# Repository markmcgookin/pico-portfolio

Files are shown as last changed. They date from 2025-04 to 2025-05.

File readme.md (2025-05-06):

# The Pico Portfolio

This project is an attempt to create a maker-friendly keyboard using the same form factor as the original Atari Portfolio keyboard. 

What started out as an attempt to re-use broken atari portfolio keyboards in new/modern projects hit a wall when tryign to remove the keyboard from its original housing. The housing on the actual Atari Portfolio is very custom for the device and case, and doesn't lend itself well to re-modeling, due to the makeup of the matrix, individual keys and rubber membrane. 

There are files here (in original-portfolio-files) that can be used to turn a *real* atari portfolio keyboard into a USB device with a Raspberry Pi Pico, however, the aim of this repo is to simply create a new, custom board that requires no legacy hardware, is maker friendly, and can be customised with only a 3D printer and some circuitpython.

## Why the portfolio?

Because of its form factor, it is somewhere between the very popular 'blackberry' style handheld keyboard, and the smallest ortholiniar keyboards used in maker projects like cyberdecks. This gives a full keyboard with modifier keys, sacrificing 'touch typing' ability for ease of use by someone who is not an expert in multi-layer keyboard setups. 

Also, John Connor hacked an ATM with one in T2 and I have been in love with them ever since. 

## Why the pico? 

Basically, I had a few picow's lying around and I know the device well. It has lots of GPIO pins and pads under the USB port that make it very easy to solder wires to use as a neat form factor for this sort of thing. 

## Why circuitpython

I plan to add a QMK version to this in the future, and I don't think it would be too hard, but when writing my original version of the firmware for the *real* Portfolio keyboard I ended up using CircuitPython because I knew/understood it well, and was able to make progress. My initial attempts at QMK for that build failed, so I've just stuck with it as it makes debugging super easy. I personally prefer it to MicroPython, but if anyone wants to translate it, please be my guest.

However, now that I know the exact matrix setup, I think QMK would be pretty easy to add to this as an option as well. 

# Setup
You will need to flash a Pico with CircuitPython 9.X (at the time of writing I am using 9.2.7 for the PicoW) - once that is done, connect it to your computer and drop all the files/folders in the `device` folder onto the device. That should load up everything required.

Then it is a matter of printing the STLs in the `3d-models -> stls -> buttons` folder or creating your own. I have included backups of my Fusion360 project in `3d-models -> fusion` should anyone wish to modify things and export their own. I will also include models for the circuitboard with switches and pico in place hopefully will help people wanting to make their own.

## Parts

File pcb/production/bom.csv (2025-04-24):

Designator | Footprint | Quantity | Value | LCSC Part #
D1, D10, D11, D12, D13, D14, D15, D16, D17, D18, D19, D2, D20, D21, D22, D23, D24, D25, D26, D27, D28, D29, D3, D30, D31, D32, D33, D34, D35, D36, D37, D38, D39, D4, D40, D41, D42, D43, D44, D45, D46, D47, D48, D49, D5, D50, D51, D52, D53, D54, D55, D56, D57, D58, D59, D6, D60, D61, D62, D63, D64, D7, D8, D9 | SOD-123_L2.8-W1.8-LS3.7-RD | 64 | 1N4148
SW1, SW10, SW11, SW12, SW13, SW14, SW15, SW16, SW17, SW18, SW19, SW2, SW20, SW21, SW22, SW23, SW24, SW25, SW26, SW27, SW28, SW29, SW3, SW30, SW31, SW32, SW33, SW34, SW35, SW36, SW37, SW38, SW39, SW4, SW40, SW41, SW42, SW43, SW44, SW45, SW46, SW47, SW48, SW49, SW5, SW50, SW51, SW52, SW53, SW54, SW55, SW56, SW57, SW58, SW59, SW6, SW60, SW61, SW62, SW63, SW64, SW7, SW8, SW9 | SW-SMD_4P-L6.2-W6.2-P4.50-LS8.6 | 64 | SW_Push

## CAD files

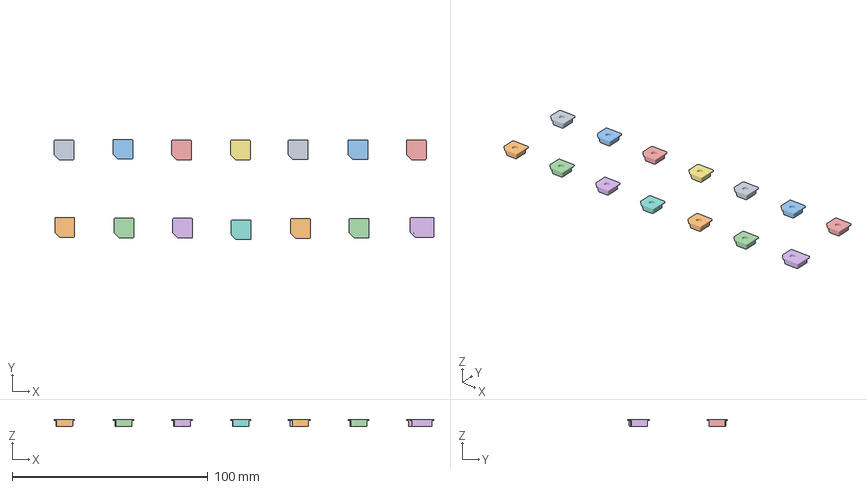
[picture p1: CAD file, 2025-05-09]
3d-models/printing/Top Row - With Lettering.3mf
194.3 x 51.4 x 3.60 mm
Pico Portfolio Keyboard With Keys v48.stl_1
Pico Portfolio Keyboard With Keys v48.stl_2
Pico Portfolio Keyboard With Keys v48.stl_3
Pico Portfolio Keyboard With Keys v48.stl_4
Pico Portfolio Keyboard With Keys v48.stl_5
Pico Portfolio Keyboard With Keys v48.stl_6
Pico Portfolio Keyboard With Keys v48.stl_7
Pico Portfolio Keyboard With Keys v48.stl_8
Pico Portfolio Keyboard With Keys v48.stl_9
Pico Portfolio Keyboard With Keys v48.stl_10
Pico Portfolio Keyboard With Keys v48.stl_11
Pico Portfolio Keyboard With Keys v48.stl_12
Pico Portfolio Keyboard With Keys v48.stl_13
Pico Portfolio Keyboard With Keys v48.stl_14
Pico Portfolio Keyboard With Keys v48.stl_15
Pico Portfolio Keyboard With Keys v48.stl_16
Pico Portfolio Keyboard With Keys v48.stl_17
Pico Portfolio Keyboard With Keys v48.stl_18
Pico Portfolio Keyboard With Keys v48.stl_19
Pico Portfolio Keyboard With Keys v48.stl_20
Pico Portfolio Keyboard With Keys v48.stl_21
Pico Portfolio Keyboard With Keys v48.stl_22
Pico Portfolio Keyboard With Keys v48.stl_23
Pico Portfolio Keyboard With Keys v48.stl_24
Pico Portfolio Keyboard With Keys v48.stl_25
Pico Portfolio Keyboard With Keys v48.stl_26
Pico Portfolio Keyboard With Keys v48.stl_27
Pico Portfolio Keyboard With Keys v48.stl_28
Pico Portfolio Keyboard With Keys v48.stl_29
Pico Portfolio Keyboard With Keys v48.stl_30
Pico Portfolio Keyboard With Keys v48.stl_31
Pico Portfolio Keyboard With Keys v48.stl_32
Pico Portfolio Keyboard With Keys v48.stl_33
Pico Portfolio Keyboard With Keys v48.stl_34
Pico Portfolio Keyboard With Keys v48.stl_35
Pico Portfolio Keyboard With Keys v48.stl_36
Pico Portfolio Keyboard With Keys v48.stl_37
Pico Portfolio Keyboard With Keys v48.stl_38
Pico Portfolio Keyboard With Keys v48.stl_39
Pico Portfolio Keyboard With Keys v48.stl_40
Pico Portfolio Keyboard With Keys v48.stl_41
Pico Portfolio Keyboard With Keys v48.stl_42
Pico Portfolio Keyboard With Keys v48.stl_43
Pico Portfolio Keyboard With Keys v48.stl_44
Pico Portfolio Keyboard With Keys v48.stl_45
Pico Portfolio Keyboard With Keys v48.stl_46

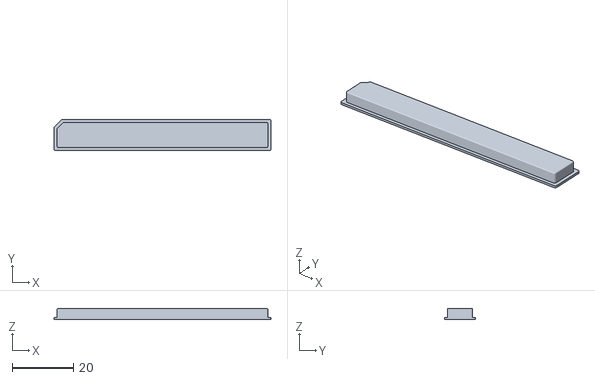
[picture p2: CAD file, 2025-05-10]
3d-models/stls/Spacebar.stl
71.0 x 10.2 x 3.60

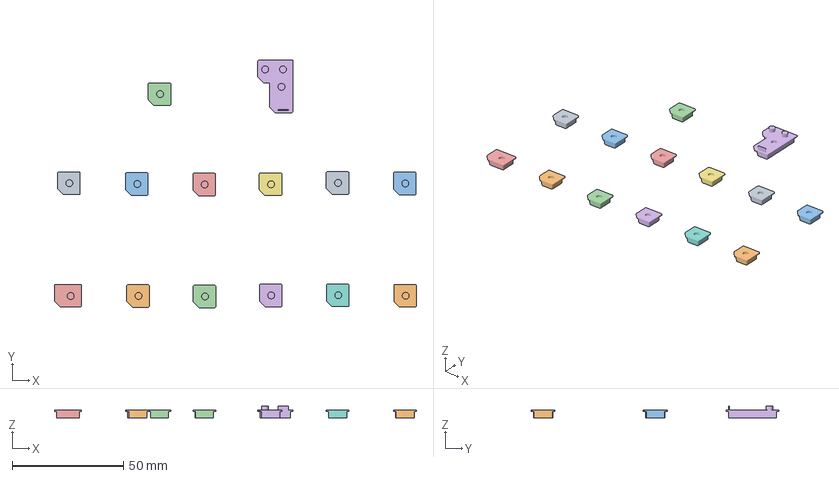
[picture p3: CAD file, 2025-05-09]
3d-models/printing/Second Row - With Lettering.3mf
162.7 x 111.4 x 5.60 mm
Pico Portfolio Keyboard With Keys v50.stl_1
Pico Portfolio Keyboard With Keys v50.stl_2
Pico Portfolio Keyboard With Keys v50.stl_3
Pico Portfolio Keyboard With Keys v50.stl_4
Pico Portfolio Keyboard With Keys v50.stl_5
Pico Portfolio Keyboard With Keys v50.stl_6
Pico Portfolio Keyboard With Keys v50.stl_7
Pico Portfolio Keyboard With Keys v50.stl_8
Pico Portfolio Keyboard With Keys v50.stl_9
Pico Portfolio Keyboard With Keys v50.stl_10
Pico Portfolio Keyboard With Keys v50.stl_11
Pico Portfolio Keyboard With Keys v50.stl_12
Pico Portfolio Keyboard With Keys v50.stl_13
Pico Portfolio Keyboard With Keys v50.stl_14
Pico Portfolio Keyboard With Keys v50.stl_15
Pico Portfolio Keyboard With Keys v50.stl_16
Pico Portfolio Keyboard With Keys v50.stl_17
Pico Portfolio Keyboard With Keys v50.stl_18
Pico Portfolio Keyboard With Keys v50.stl_19
Pico Portfolio Keyboard With Keys v50.stl_20
Pico Portfolio Keyboard With Keys v50.stl_21
Pico Portfolio Keyboard With Keys v50.stl_22
Pico Portfolio Keyboard With Keys v50.stl_23
Pico Portfolio Keyboard With Keys v50.stl_24
Pico Portfolio Keyboard With Keys v50.stl_25
Pico Portfolio Keyboard With Keys v50.stl_26
Pico Portfolio Keyboard With Keys v50.stl_27
Pico Portfolio Keyboard With Keys v50.stl_28
Pico Portfolio Keyboard With Keys v50.stl_29
Pico Portfolio Keyboard With Keys v50.stl_30
Pico Portfolio Keyboard With Keys v50.stl_31

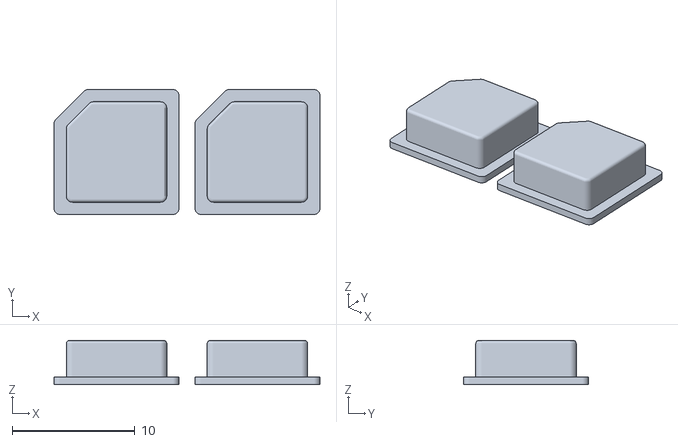
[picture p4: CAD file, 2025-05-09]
3d-models/stls/Semi Colon and Quote.stl
21.7 x 10.2 x 3.60

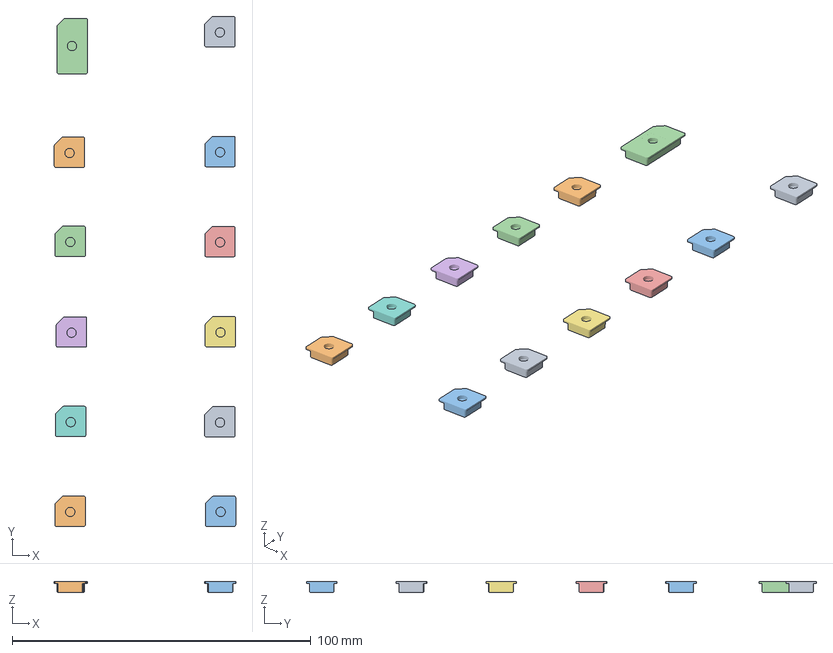
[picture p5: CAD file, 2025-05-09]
3d-models/printing/Third Row - With Lettering.3mf
60.8 x 170.8 x 3.62 mm
Third Row.stl_1
Third Row.stl_2
Third Row.stl_3
Third Row.stl_4
Third Row.stl_5
Third Row.stl_6
Third Row.stl_7
Third Row.stl_8
Third Row.stl_9
Third Row.stl_10
Third Row.stl_11
Third Row.stl_12
Third Row.stl_13
Third Row.stl_14
Third Row.stl_15
Third Row.stl_16
Third Row.stl_17
Third Row.stl_18
Third Row.stl_19
Third Row.stl_20
Third Row.stl_21
Third Row.stl_22
Third Row.stl_23
Third Row.stl_24
Third Row.stl_25
Third Row.stl_26
Third Row.stl_27
Third Row.stl_28
Third Row.stl_29
Third Row.stl_30
Third Row.stl_31
Third Row.stl_32
Third Row.stl_33

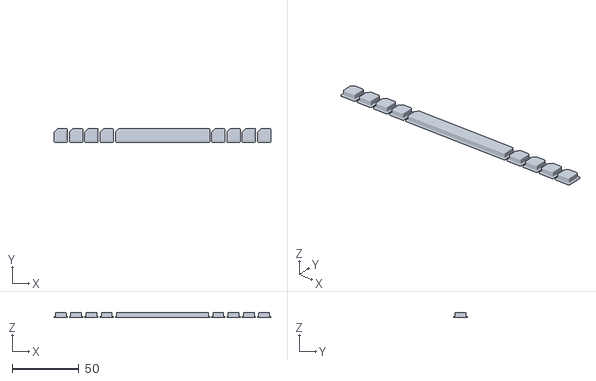
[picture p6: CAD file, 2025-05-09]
3d-models/stls/Bottom Row.stl
162.9 x 10.2 x 3.62

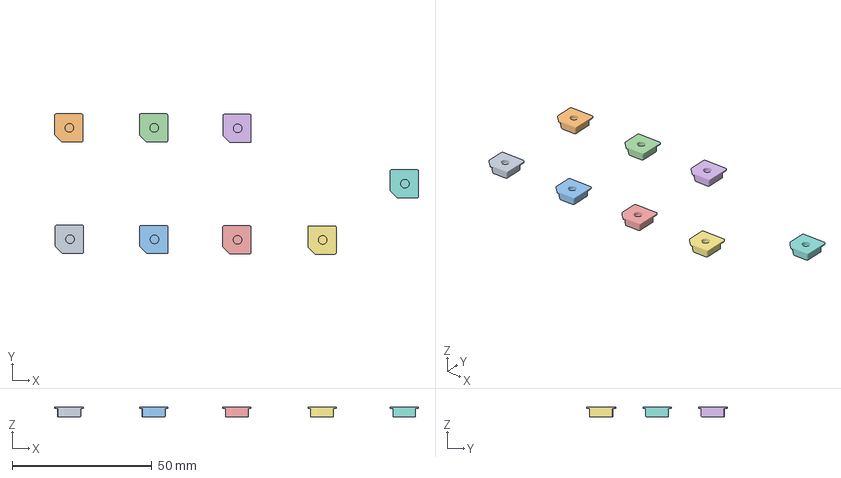
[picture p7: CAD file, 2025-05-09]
3d-models/printing/Bottom Row - With Lettering.3mf
130.5 x 50.4 x 3.60 mm
Bottom Row.stl_1
Bottom Row.stl_2
Bottom Row.stl_3
Bottom Row.stl_4
Bottom Row.stl_5
Bottom Row.stl_6
Bottom Row.stl_7
Bottom Row.stl_8
Bottom Row.stl_10
Bottom Row.stl_11
Bottom Row.stl_12
Bottom Row.stl_13
Bottom Row.stl_14
Bottom Row.stl_15
Bottom Row.stl_16
Bottom Row.stl_17
Bottom Row.stl_18
Bottom Row.stl_19
Bottom Row.stl_20
Bottom Row.stl_21
Bottom Row.stl_22
Bottom Row.stl_23
Bottom Row.stl_24
Bottom Row.stl_25

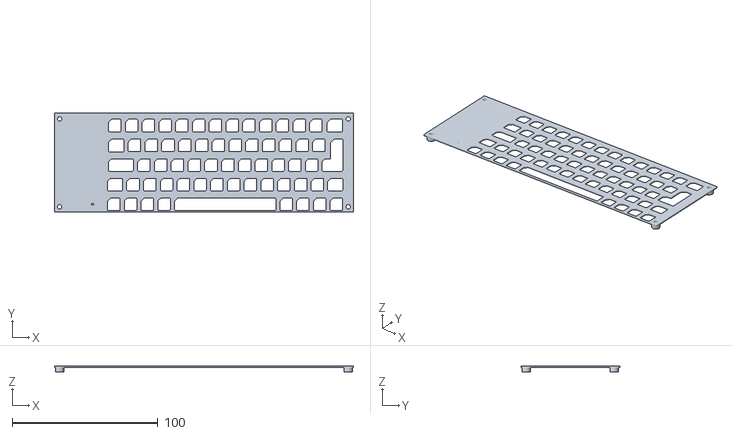
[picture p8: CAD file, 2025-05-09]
3d-models/stls/FacePlate.stl
205.1 x 68.2 x 4.40

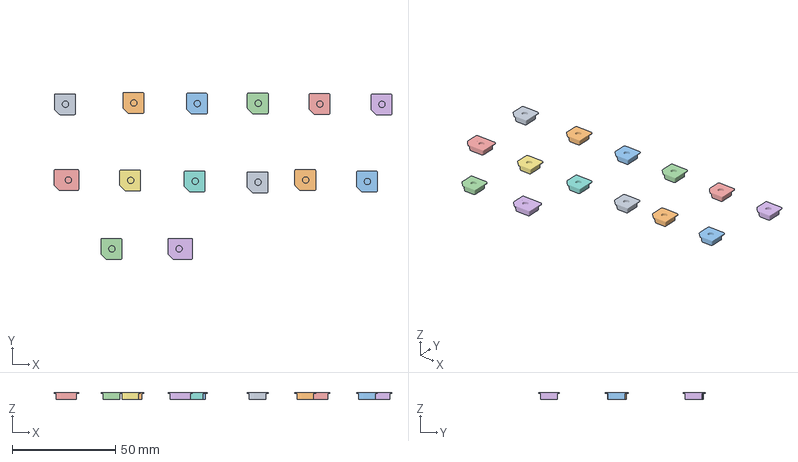
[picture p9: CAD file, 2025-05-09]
3d-models/printing/Fouth Row - With Lettering.3mf
163.8 x 80.9 x 3.60 mm
Fouth Row.stl_1
Fouth Row.stl_2
Fouth Row.stl_3
Fouth Row.stl_4
Fouth Row.stl_5
Fouth Row.stl_6
Fouth Row.stl_7
Fouth Row.stl_8
Fouth Row.stl_9
Fouth Row.stl_10
Fouth Row.stl_11
Fouth Row.stl_12
Fouth Row.stl_13
Fouth Row.stl_14
Fouth Row.stl_15
Fouth Row.stl_16
Fouth Row.stl_17
Fouth Row.stl_18
Fouth Row.stl_19
Fouth Row.stl_20
Fouth Row.stl_21
Fouth Row.stl_22
Fouth Row.stl_23
Fouth Row.stl_24
Fouth Row.stl_25
Fouth Row.stl_26
Fouth Row.stl_27
Fouth Row.stl_28
Fouth Row.stl_29
Fouth Row.stl_30
Fouth Row.stl_31
Fouth Row.stl_32
Fouth Row.stl_33
Fouth Row.stl_34
Fouth Row.stl_35
Fouth Row.stl_36
Fouth Row.stl_37
Fouth Row.stl_38

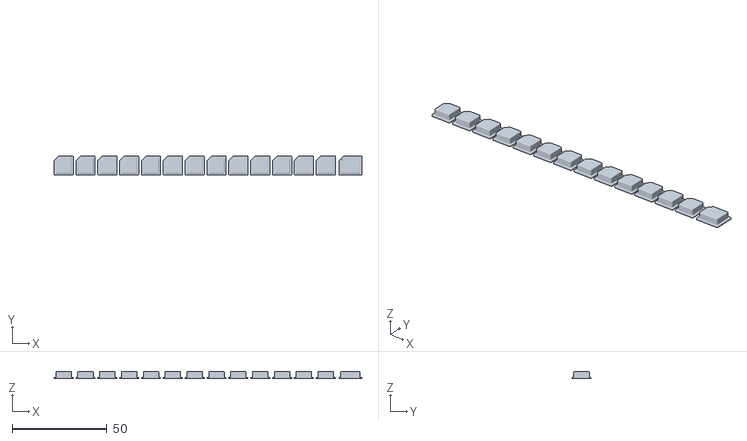
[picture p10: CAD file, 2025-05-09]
3d-models/stls/Top Row.stl
162.2 x 10.2 x 3.62

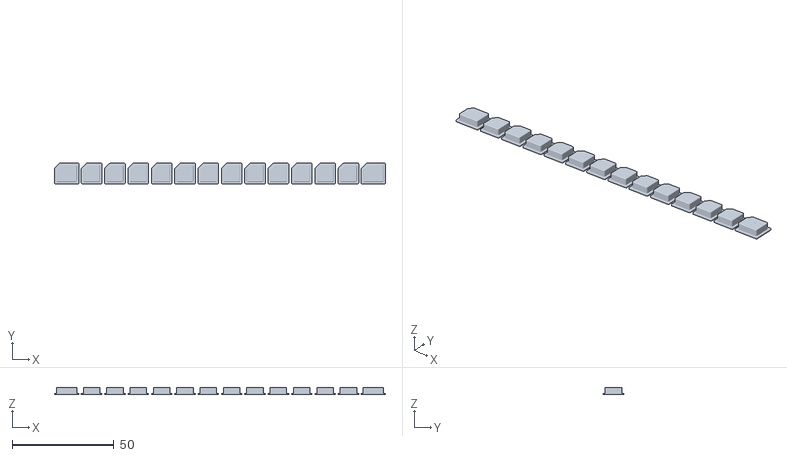
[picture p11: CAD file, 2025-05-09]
3d-models/stls/Fouth Row.stl
163.0 x 10.2 x 3.62

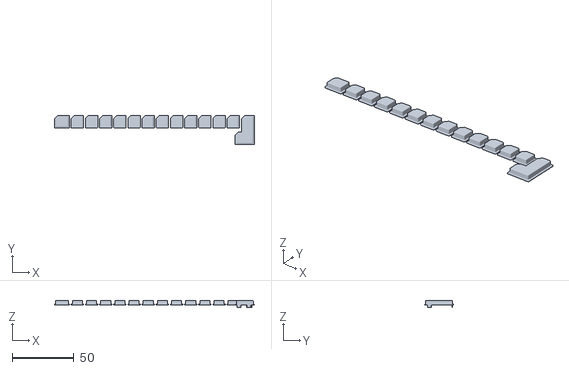
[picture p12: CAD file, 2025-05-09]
3d-models/stls/Second Row.stl
162.3 x 23.7 x 5.67

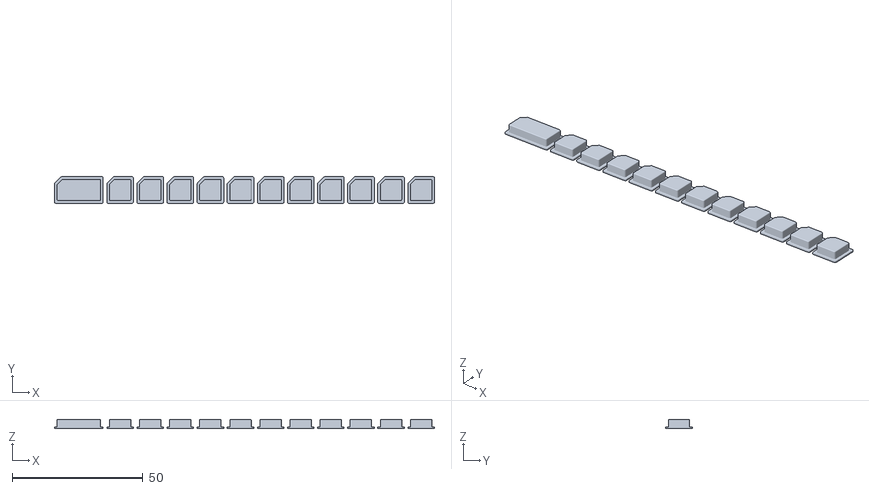
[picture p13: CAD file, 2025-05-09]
3d-models/stls/Third Row.stl
145.2 x 10.2 x 3.62

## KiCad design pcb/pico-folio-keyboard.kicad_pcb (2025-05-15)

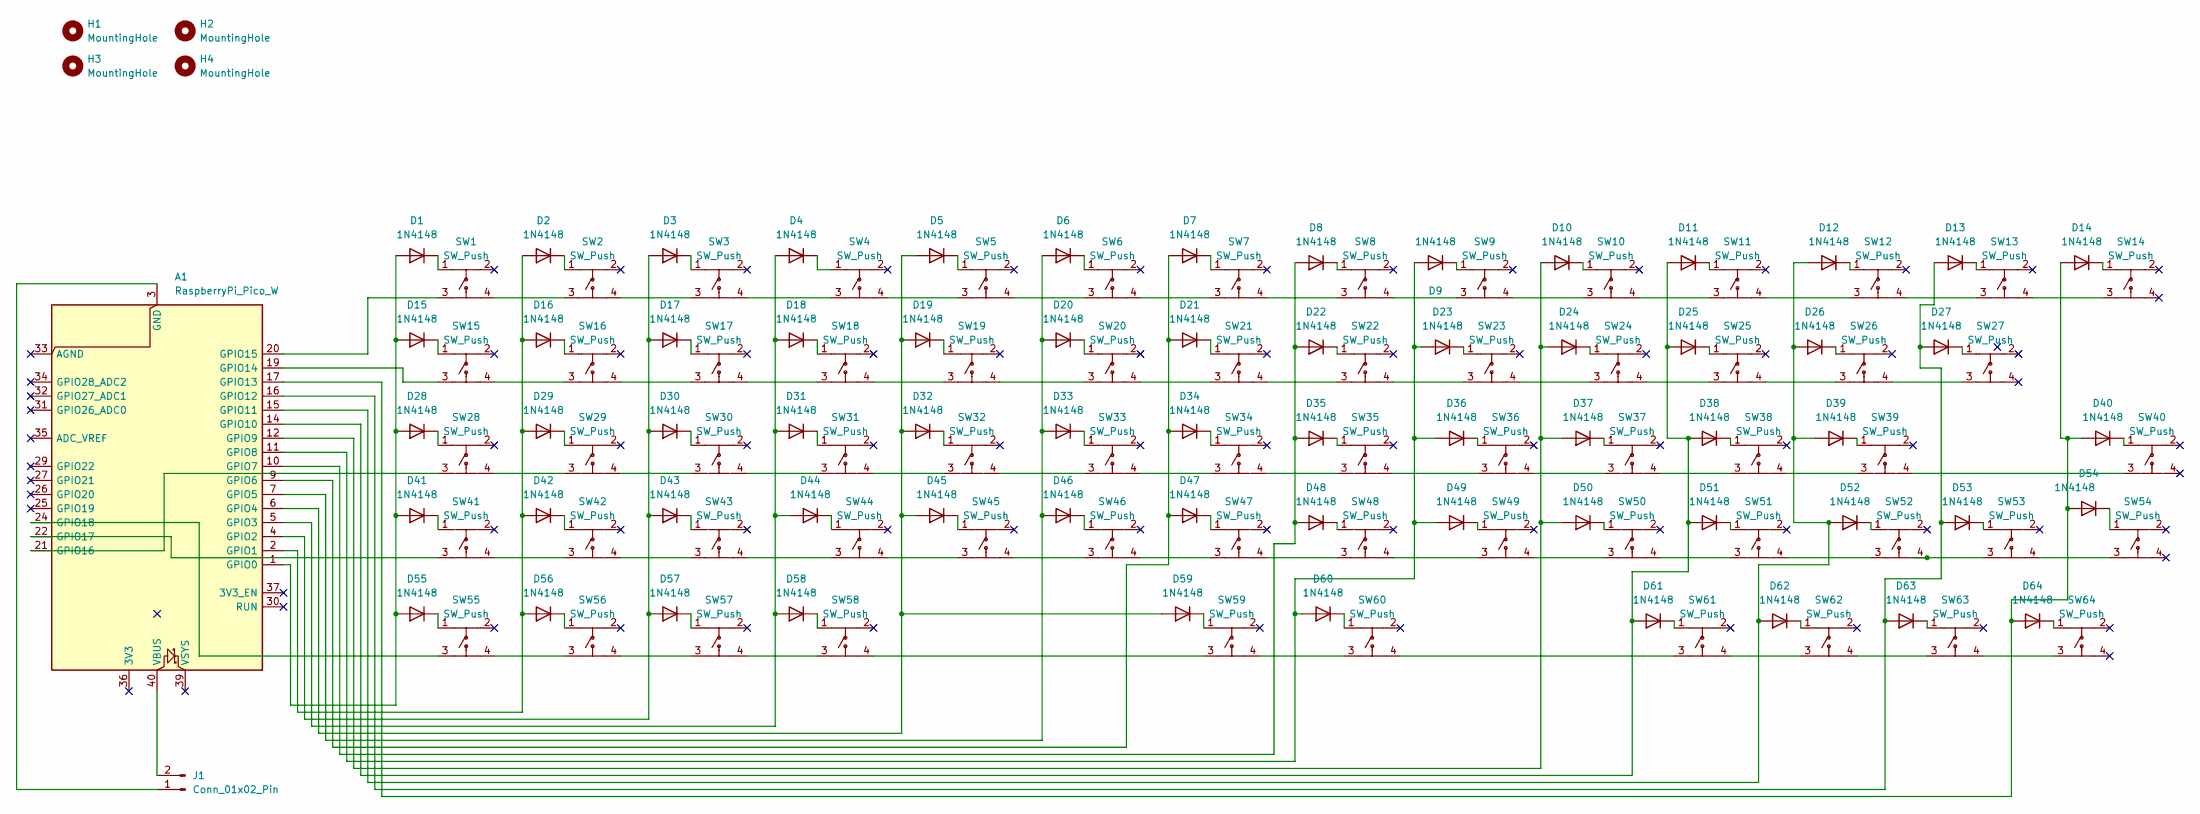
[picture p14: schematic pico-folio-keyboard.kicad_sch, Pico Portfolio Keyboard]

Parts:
A1: RaspberryPi_Pico_W; RaspberryPi_Pico_W_SMD_HandSolder
D1, D2, D3, D4, D5, D6, D7, D8, D9, D10, D11, D12, D13, D14, D15, D16, D17, D18, D19, D20, D21, D22, D23, D24, D25, D26, D27, D28, D29, D30, D31, D32, D33, D34, D35, D36, D37, D38, D39, D40, D41, D42, D43, D44, D45, D46, D47, D48, D49, D50, D51, D52, D53, D54, D55, D56, D57, D58, D59, D60, D61, D62, D63, D64: 1N4148; D_DO-35_SOD27_P7.62mm_Horizontal
H1, H2, H3, H4: MountingHole; MountingHole_2.7mm
J1: Conn_01x02_Pin; PinHeader_1x02_P2.54mm_Vertical
SW1, SW2, SW3, SW4, SW5, SW6, SW7, SW8, SW9, SW10, SW11, SW12, SW13, SW14, SW15, SW16, SW17, SW18, SW19, SW20, SW21, SW22, SW23, SW24, SW25, SW26, SW27, SW28, SW29, SW30, SW31, SW32, SW33, SW34, SW35, SW36, SW37, SW38, SW39, SW40, SW41, SW42, SW43, SW44, SW45, SW46, SW47, SW48, SW49, SW50, SW51, SW52, SW53, SW54, SW55, SW56, SW57, SW58, SW59, SW60, SW61, SW62, SW63, SW64: SW_Push; SW-SMD_4P-L6.2-W6.2-P4.50-LS8.6; Manufacturer Part K2-1157SP-I4SW-01; LCSC Part Name 6.4x6.2x3.7红柄开关

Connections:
unnamed: A1.1 (GPIO0), D1.2 (A), D15.2 (A), D28.2 (A), D41.2 (A), D55.2 (A)
unnamed: A1.2 (GPIO1), D2.2 (A), D16.2 (A), D29.2 (A), D42.2 (A), D56.2 (A)
unnamed: A1.4 (GPIO2), D3.2 (A), D17.2 (A), D30.2 (A), D43.2 (A), D57.2 (A)
unnamed: A1.5 (GPIO3), D4.2 (A), D18.2 (A), D31.2 (A), D44.2 (A), D58.2 (A)
unnamed: A1.6 (GPIO4), D5.2 (A), D19.2 (A), D32.2 (A), D45.2 (A), D59.2 (A)
unnamed: A1.7 (GPIO5), D6.2 (A), D20.2 (A), D33.2 (A), D46.2 (A)
unnamed: A1.9 (GPIO6), D7.2 (A), D21.2 (A), D34.2 (A), D47.2 (A)
unnamed: A1.10 (GPIO7), D8.2 (A), D22.2 (A), D35.2 (A), D48.2 (A)
unnamed: A1.11 (GPIO8), D9.2 (A), D23.2 (A), D36.2 (A), D49.2 (A), D60.2 (A)
unnamed: A1.12 (GPIO9), D10.2 (A), D24.2 (A), D37.2 (A), D50.2 (A)
unnamed: A1.14 (GPIO10), D11.2 (A), D25.2 (A), D38.2 (A), D51.2 (A), D61.2 (A)
unnamed: A1.15 (GPIO11), D12.2 (A), D26.2 (A), D39.2 (A), D52.2 (A), D62.2 (A)
unnamed: A1.16 (GPIO12), D13.2 (A), D27.2 (A), D53.2 (A), D63.2 (A)
unnamed: A1.17 (GPIO13), D14.2 (A), D40.2 (A), D54.2 (A), D64.2 (A)
unnamed: A1.19 (GPIO14), SW15.3
unnamed: A1.20 (GPIO15), SW1.3
unnamed: A1.21 (GPIO16), SW28.3
unnamed: A1.22 (GPIO17), SW41.3
unnamed: A1.24 (GPIO18), SW55.3
unnamed: A1.40 (VBUS), J1.2
unnamed: D1.1 (K), SW1.1
unnamed: D2.1 (K), SW2.1
unnamed: D3.1 (K), SW3.1
unnamed: D4.1 (K), SW4.1
unnamed: D5.1 (K), SW5.1
unnamed: D6.1 (K), SW6.1
unnamed: D7.1 (K), SW7.1
unnamed: D8.1 (K), SW8.1
unnamed: D9.1 (K), SW9.1
unnamed: D10.1 (K), SW10.1
unnamed: D11.1 (K), SW11.1
unnamed: D12.1 (K), SW12.1
unnamed: D13.1 (K), SW13.1
unnamed: D14.1 (K), SW14.1
unnamed: D15.1 (K), SW15.1
unnamed: D16.1 (K), SW16.1
unnamed: D17.1 (K), SW17.1
unnamed: D18.1 (K), SW18.1
unnamed: D19.1 (K), SW19.1
unnamed: D20.1 (K), SW20.1
unnamed: D21.1 (K), SW21.1
unnamed: D22.1 (K), SW22.1
unnamed: D23.1 (K), SW23.1
unnamed: D24.1 (K), SW24.1
unnamed: D25.1 (K), SW25.1
unnamed: D26.1 (K), SW26.1
unnamed: D27.1 (K), SW27.1
unnamed: D28.1 (K), SW28.1
unnamed: D29.1 (K), SW29.1
unnamed: D30.1 (K), SW30.1
unnamed: D31.1 (K), SW31.1
unnamed: D32.1 (K), SW32.1
unnamed: D33.1 (K), SW33.1
unnamed: D34.1 (K), SW34.1
unnamed: D35.1 (K), SW35.1
unnamed: D36.1 (K), SW36.1
unnamed: D37.1 (K), SW37.1
unnamed: D38.1 (K), SW38.1
unnamed: D39.1 (K), SW39.1
unnamed: D40.1 (K), SW40.1
unnamed: D41.1 (K), SW41.1
unnamed: D42.1 (K), SW42.1
unnamed: D43.1 (K), SW43.1
unnamed: D44.1 (K), SW44.1
unnamed: D45.1 (K), SW45.1
unnamed: D46.1 (K), SW46.1
unnamed: D47.1 (K), SW47.1
unnamed: D48.1 (K), SW48.1
unnamed: D49.1 (K), SW49.1
unnamed: D50.1 (K), SW50.1
unnamed: D51.1 (K), SW51.1
unnamed: D52.1 (K), SW52.1
unnamed: D53.1 (K), SW53.1
unnamed: D54.1 (K), SW54.1
unnamed: D55.1 (K), SW55.1
unnamed: D56.1 (K), SW56.1
unnamed: D57.1 (K), SW57.1
unnamed: D58.1 (K), SW58.1
unnamed: D59.1 (K), SW59.1
unnamed: D60.1 (K), SW60.1
unnamed: D61.1 (K), SW61.1
unnamed: D62.1 (K), SW62.1
unnamed: D63.1 (K), SW63.1
unnamed: D64.1 (K), SW64.1
unnamed: A1.3 (GND), A1.8 (GND), A1.13 (GND), A1.18 (GND), A1.23 (GND), A1.28 (GND), A1.38 (GND), J1.1
unnamed: SW1.4, SW2.3
unnamed: SW2.4, SW3.3
unnamed: SW3.4, SW4.3
unnamed: SW4.4, SW5.3
unnamed: SW5.4, SW6.3
unnamed: SW6.4, SW7.3
unnamed: SW7.4, SW8.3
unnamed: SW8.4, SW9.3
unnamed: SW9.4, SW10.3
unnamed: SW10.4, SW11.3
unnamed: SW11.4, SW12.3
unnamed: SW12.4, SW13.3
unnamed: SW13.4, SW14.3
unnamed: SW15.4, SW16.3
unnamed: SW16.4, SW17.3
unnamed: SW17.4, SW18.3
unnamed: SW18.4, SW19.3
unnamed: SW19.4, SW20.3
unnamed: SW20.4, SW21.3
unnamed: SW21.4, SW22.3
unnamed: SW22.4, SW23.3
unnamed: SW23.4, SW24.3
unnamed: SW24.4, SW25.3
unnamed: SW25.4, SW26.3
unnamed: SW26.4, SW27.3
unnamed: SW28.4, SW29.3
unnamed: SW29.4, SW30.3
unnamed: SW30.4, SW31.3
unnamed: SW31.4, SW32.3
unnamed: SW32.4, SW33.3
unnamed: SW33.4, SW34.3
unnamed: SW34.4, SW35.3
unnamed: SW35.4, SW36.3
unnamed: SW36.4, SW37.3
unnamed: SW37.4, SW38.3
unnamed: SW38.4, SW39.3
unnamed: SW39.4, SW40.3
unnamed: SW41.4, SW42.3
unnamed: SW42.4, SW43.3
unnamed: SW43.4, SW44.3
unnamed: SW44.4, SW45.3
unnamed: SW45.4, SW46.3
unnamed: SW46.4, SW47.3
unnamed: SW47.4, SW48.3
unnamed: SW48.4, SW49.3
unnamed: SW49.4, SW50.3
unnamed: SW50.4, SW51.3
unnamed: SW51.4, SW52.3
unnamed: SW52.4, SW53.3
unnamed: SW53.4, SW54.3
unnamed: SW55.4, SW56.3
unnamed: SW56.4, SW57.3
unnamed: SW57.4, SW58.3
unnamed: SW58.4, SW59.3
unnamed: SW59.4, SW60.3
unnamed: SW60.4, SW61.3
unnamed: SW61.4, SW62.3
unnamed: SW62.4, SW63.3
unnamed: SW63.4, SW64.3

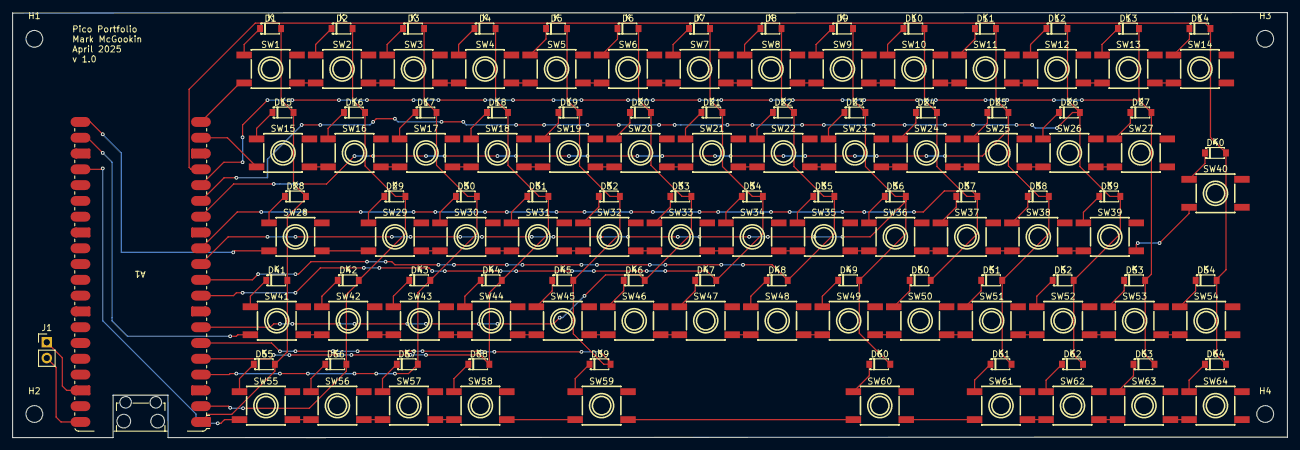
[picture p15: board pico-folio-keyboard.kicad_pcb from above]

Board: 2 copper layers, 205.1 x 68.4 mm, 134 parts (0 on the bottom side), 144 nets.

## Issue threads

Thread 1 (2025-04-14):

CAPS LOCK - Not working

markmcgookin, 2025-04-14:
Need a caps lock toggle function, and possibly an LED indicator

Closed 2025-05-06.

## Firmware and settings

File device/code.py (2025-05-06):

# SPDX-FileCopyrightText: 2023 Custom Keyboard Firmware
# SPDX-License-Identifier: MIT

import time
import board
import digitalio
import usb_hid
from adafruit_hid.keyboard import Keyboard
from adafruit_hid.keycode import Keycode

# Debug mode toggle - set to False for normal keyboard operation
# Set to True to only output to serial without sending keystrokes
DEBUG_MODE = True

# Initialize keyboard
keyboard = Keyboard(usb_hid.devices)

# Define pins for rows based on specified connections (top to bottom)
row_pins = [board.GP15, board.GP14, board.GP16, board.GP17, board.GP18]  # 5 rows

# Define pins for columns (left to right)
col_pins = [
    board.GP0, board.GP1, board.GP2, board.GP3, board.GP4, board.GP5,
    board.GP6, board.GP7, board.GP8, board.GP9, board.GP10, board.GP11,
    board.GP12, board.GP13  # 14 columns
]

# Setup rows as outputs with initial HIGH state
rows = []
for pin in row_pins:
    row = digitalio.DigitalInOut(pin)
    row.direction = digitalio.Direction.OUTPUT
    row.drive_mode = digitalio.DriveMode.PUSH_PULL
    row.value = True  # Set HIGH initially (inactive)
    rows.append(row)

# Setup columns as inputs with pull-up resistors
cols = []
for pin in col_pins:
    col = digitalio.DigitalInOut(pin)
    col.direction = digitalio.Direction.INPUT
    col.pull = digitalio.Pull.UP  # Pull-UP for diode-to-switch configuration
    cols.append(col)

# Define a dictionary to map keycode values to names
# This replaces the vars(Keycode) approach that's not available in CircuitPython
KEYCODE_NAMES = {
    Keycode.A: "A", Keycode.B: "B", Keycode.C: "C", Keycode.D: "D",
    Keycode.E: "E", Keycode.F: "F", Keycode.G: "G", Keycode.H: "H",
    Keycode.I: "I", Keycode.J: "J", Keycode.K: "K", Keycode.L: "L",
    Keycode.M: "M", Keycode.N: "N", Keycode.O: "O", Keycode.P: "P",
    Keycode.Q: "Q", Keycode.R: "R", Keycode.S: "S", Keycode.T: "T",
    Keycode.U: "U", Keycode.V: "V", Keycode.W: "W", Keycode.X: "X",
    Keycode.Y: "Y", Keycode.Z: "Z",
    Keycode.ONE: "1", Keycode.TWO: "2", Keycode.THREE: "3", Keycode.FOUR: "4",
    Keycode.FIVE: "5", Keycode.SIX: "6", Keycode.SEVEN: "7", Keycode.EIGHT: "8",
    Keycode.NINE: "9", Keycode.ZERO: "0",
    Keycode.ENTER: "ENTER", Keycode.RETURN: "RETURN", Keycode.ESCAPE: "ESC",
    Keycode.BACKSPACE: "BACKSPACE", Keycode.TAB: "TAB", Keycode.SPACEBAR: "SPACE",
    Keycode.SPACE: "SPACE", Keycode.MINUS: "MINUS", Keycode.EQUALS: "EQUALS",
    Keycode.LEFT_BRACKET: "LEFT_BRACKET", Keycode.RIGHT_BRACKET: "RIGHT_BRACKET",
    Keycode.BACKSLASH: "BACKSLASH", Keycode.SEMICOLON: "SEMICOLON",
    Keycode.QUOTE: "QUOTE", Keycode.GRAVE_ACCENT: "GRAVE",
    Keycode.COMMA: "COMMA", Keycode.PERIOD: "PERIOD", Keycode.FORWARD_SLASH: "SLASH",
    Keycode.CAPS_LOCK: "CAPS_LOCK",
    Keycode.F1: "F1", Keycode.F2: "F2", Keycode.F3: "F3", Keycode.F4: "F4",
    Keycode.F5: "F5", Keycode.F6: "F6", Keycode.F7: "F7", Keycode.F8: "F8",
    Keycode.F9: "F9", Keycode.F10: "F10", Keycode.F11: "F11", Keycode.F12: "F12",
    Keycode.PRINT_SCREEN: "PRINT_SCREEN", Keycode.SCROLL_LOCK: "SCROLL_LOCK",
    Keycode.PAUSE: "PAUSE", Keycode.INSERT: "INSERT", Keycode.HOME: "HOME",
    Keycode.PAGE_UP: "PAGE_UP", Keycode.DELETE: "DELETE", Keycode.END: "END",
    Keycode.PAGE_DOWN: "PAGE_DOWN", Keycode.RIGHT_ARROW: "RIGHT",
    Keycode.LEFT_ARROW: "LEFT", Keycode.DOWN_ARROW: "DOWN", Keycode.UP_ARROW: "UP",
    Keycode.KEYPAD_NUMLOCK: "NUM_LOCK", Keycode.KEYPAD_FORWARD_SLASH: "KP_SLASH",
    Keycode.KEYPAD_ASTERISK: "KP_ASTERISK", Keycode.KEYPAD_MINUS: "KP_MINUS",
    Keycode.KEYPAD_PLUS: "KP_PLUS", Keycode.KEYPAD_ENTER: "KP_ENTER",
    Keycode.KEYPAD_ONE: "KP_1", Keycode.KEYPAD_TWO: "KP_2", Keycode.KEYPAD_THREE: "KP_3",
    Keycode.KEYPAD_FOUR: "KP_4", Keycode.KEYPAD_FIVE: "KP_5", Keycode.KEYPAD_SIX: "KP_6",
    Keycode.KEYPAD_SEVEN: "KP_7", Keycode.KEYPAD_EIGHT: "KP_8", Keycode.KEYPAD_NINE: "KP_9",
    Keycode.KEYPAD_ZERO: "KP_0", Keycode.KEYPAD_PERIOD: "KP_PERIOD",
    Keycode.LEFT_CONTROL: "LEFT_CTRL", Keycode.LEFT_SHIFT: "LEFT_SHIFT",
    Keycode.LEFT_ALT: "LEFT_ALT", Keycode.LEFT_GUI: "LEFT_GUI",
    Keycode.RIGHT_CONTROL: "RIGHT_CTRL", Keycode.RIGHT_SHIFT: "RIGHT_SHIFT",
    Keycode.RIGHT_ALT: "RIGHT_ALT", Keycode.RIGHT_GUI: "RIGHT_GUI"
}

# Helper function to get keycode name from the Keycode value
def get_keycode_name(keycode_value):
    return KEYCODE_NAMES.get(keycode_value, f"UNKNOWN({keycode_value})")

# Define the keymap - 5 rows x 14 columns
# You can customize this with the specific keycodes you want for each position
keymap = [
    # Row 0 (top row)
    [Keycode.ESCAPE, Keycode.ONE, Keycode.TWO, Keycode.THREE, Keycode.FOUR, Keycode.FIVE,
     Keycode.SIX, Keycode.SEVEN, Keycode.EIGHT, Keycode.NINE, Keycode.ZERO,
     Keycode.MINUS, Keycode.EQUALS, Keycode.BACKSPACE],

    # Row 1
    [Keycode.TAB, Keycode.Q, Keycode.W, Keycode.E, Keycode.R, Keycode.T,
     Keycode.Y, Keycode.U, Keycode.I, Keycode.O, Keycode.P,
     Keycode.LEFT_BRACKET, Keycode.RIGHT_BRACKET, Keycode.BACKSLASH],

    # Row 2
    [Keycode.CAPS_LOCK, Keycode.A, Keycode.S, Keycode.D, Keycode.F, Keycode.G,
     Keycode.H, Keycode.J, Keycode.K, Keycode.L, Keycode.SEMICOLON,
     Keycode.QUOTE, Keycode.ENTER, Keycode.DELETE],

    # Row 3
    [Keycode.LEFT_SHIFT, Keycode.Z, Keycode.X, Keycode.C, Keycode.V, Keycode.B,
     Keycode.N, Keycode.M, Keycode.COMMA, Keycode.PERIOD, Keycode.FORWARD_SLASH,
     Keycode.RIGHT_SHIFT, Keycode.UP_ARROW, Keycode.PAGE_UP],

    # Row 4 (bottom row)
    [Keycode.LEFT_CONTROL, Keycode.LEFT_ALT, Keycode.LEFT_GUI, Keycode.SPACE, Keycode.SPACE, Keycode.SPACE,
     Keycode.SPACE, Keycode.SPACE, Keycode.RIGHT_ALT, Keycode.RIGHT_CONTROL, Keycode.LEFT_ARROW,
     Keycode.DOWN_ARROW, Keycode.RIGHT_ARROW, Keycode.PAGE_DOWN]
]

# Keep track of the currently pressed keys
key_state = [[False for _ in range(len(col_pins))] for _ in range(len(row_pins))]

# Debounce time (in seconds)
DEBOUNCE_TIME = 0.01

# Last scan time for rate limiting
last_scan = time.monotonic()
scan_interval = 0.01  # 10ms between scans

print("Keyboard firmware initialized")
print(f"DEBUG MODE: {'ON' if DEBUG_MODE else 'OFF'}")
print(f"{'ONLY SERIAL OUTPUT' if DEBUG_MODE else 'NORMAL KEYBOARD OPERATION'}")

while True:
    current_time = time.monotonic()

    # Rate limiting to avoid overwhelming USB host
    if current_time - last_scan < scan_interval:
        continue

    last_scan = current_time

    # Scan the matrix
    for r in range(len(rows)):
        # Set current row LOW (active)
        rows[r].value = False
        time.sleep(0.001)  # Brief delay for electrical settling

        for c in range(len(cols)):
            # Read the column (LOW means key pressed with diode)
            key_pressed = not cols[c].value

            # Detect key state changes
            if key_pressed != key_state[r][c]:
                # Debounce
                time.sleep(DEBOUNCE_TIME)

                # Check again after debounce time
                key_pressed_debounced = not cols[c].value

                if key_pressed_debounced != key_state[r][c]:
                    # State has genuinely changed
                    key_state[r][c] = key_pressed_debounced
                    key_value = keymap[r][c]
                    key_name = get_keycode_name(key_value)

                    if key_pressed_debounced:
                        # Key pressed
                        print(f"Key pressed: Row {r}, Column {c} - {key_name}")

                        # Only send keystrokes if not in debug mode
                        if not DEBUG_MODE:
                            keyboard.press(key_value)
                    else:
                        # Key released
                        print(f"Key released: Row {r}, Column {c} - {key_name}")

                        # Only send keystrokes if not in debug mode
                        if not DEBUG_MODE:
                            keyboard.release(key_value)

        # Set row back to HIGH (inactive)
        rows[r].value = True

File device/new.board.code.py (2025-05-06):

 # Write your code here :-)
import time
import board
import digitalio
import usb_hid
from adafruit_hid.keyboard import Keyboard
from adafruit_hid.keycode import Keycode

#optional delay before creating the HID for maximum compatibility
time.sleep(1)

#create the HID
kbd = Keyboard(usb_hid.devices)

# Define pins for rows based on your specified connections (top to bottom)
row_pins = [board.GP15, board.GP14, board.GP16, board.GP17, board.GP18]  # 5 rows
row_names = ["GP15", "GP14", "GP16", "GP17", "GP18"]

#set up the row, column, and modifier arrays
rows = []
for row in row_pins:
    row_key = digitalio.DigitalInOut(row)
    row_key.direction = digitalio.Direction.OUTPUT
    rows.append(row_key)

# Define pins for columns (left to right)
col_pins = [
    board.GP0, board.GP1, board.GP2, board.GP3, board.GP4, board.GP5,
    board.GP6, board.GP7, board.GP8, board.GP9, board.GP10, board.GP11,
    board.GP12, board.GP13  # 14 columns
]
col_names = ["GP0", "GP1", "GP2", "GP3", "GP4", "GP5", "GP6", "GP7",
             "GP8", "GP9", "GP10", "GP11", "GP12", "GP13"]

columns = []
for column in column_pins:
    column_key = digitalio.DigitalInOut(column)
    column_key.direction = digitalio.Direction.INPUT
    column_key.pull = digitalio.Pull.DOWN
    columns.append(column_key)

#array of modifier keycodes
# mod_keymap = [Keycode.LEFT_GUI,None,None,None,None,None,None,None,None,Keycode.LEFT_ALT,None,None,None,None,None,None,
#             None,None,Keycode.LEFT_CONTROL,None,None,None,None,None,None,None,None,Keycode.LEFT_SHIFT,None,None,
#             None,None,None,None,None,None,None,None,None,None,None,None,None,
#             None,None,None,None,None,None,None,None,None,None,None,
#             Keycode.F24,None,None,None,None,None,None,None,None,None]

#array of keycodes; if you want to remap see: https://circuitpython.readthedocs.io/projects/hid/en/latest/api.html#adafruit-hid-keycode-keycode /'None' values have no physical connection
# keymap = [None,Keycode.DELETE,Keycode.TAB,Keycode.ZERO,Keycode.S,Keycode.F,Keycode.BACKSLASH,Keycode.C,None,None,Keycode.W,Keycode.I,Keycode.P,Keycode.H,Keycode.Z,Keycode.V,
#             Keycode.ONE,Keycode.Q,None,Keycode.MINUS,Keycode.FOUR,Keycode.J,Keycode.SPACEBAR,Keycode.B,Keycode.TWO,Keycode.U,Keycode.E,None,Keycode.G,Keycode.LEFT_ARROW,
#             Keycode.SEMICOLON,Keycode.N,Keycode.THREE,Keycode.O,Keycode.R,Keycode.LEFT_BRACKET,Keycode.RIGHT_SHIFT,Keycode.RIGHT_ARROW,Keycode.PERIOD,Keycode.M,Keycode.D,Keycode.SEVEN,Keycode.T,
#             Keycode.UP_ARROW,Keycode.DOWN_ARROW,Keycode.CAPS_LOCK,Keycode.EQUALS,Keycode.FORWARD_SLASH,Keycode.FIVE,Keycode.BACKSPACE,Keycode.ENTER,Keycode.QUOTE,Keycode.COMMA,Keycode.EIGHT,
#             None,Keycode.A,Keycode.SIX,Keycode.NINE,Keycode.Y,Keycode.RIGHT_BRACKET,Keycode.L,Keycode.K,Keycode.X,Keycode.ESCAPE]

keymap = [Keycode.ESCAPE, Keycode.ONE, Keycode.TWO, Keycode.THREE, Keycode.FOUR, Keycode.FIVE, Keycode.SIX, Keycode.SEVEN, Keycode.EIGHT, Keycode.NINE, Keycode.ZERO, Keycode.MINUS, Keycode.EQUALS, Keycode.BACKSPACE,
            None, None, None, None, None, None, None, None, None, None, None, None, None, None,
            None, None, None, None, None, None, None, None, None, None, None, None, None, None,
            None, None, None, None, None, None, None, None, None, None, None, None, None, None,
            None, None, None, None, None, None, None, None, None, None, None, None, None, None]

def ProcessFunctionKey(key):
    print("Processing Fn")
    if(key == Keycode.ONE):
        return Keycode.F1
    elif(key == Keycode.TWO):
        return Keycode.F2
    elif(key == Keycode.TWO):
        return Keycode.F2
    elif(key == Keycode.THREE):
        return Keycode.F3
    elif(key == Keycode.FOUR):
        return Keycode.F4
    elif(key == Keycode.FIVE):
        return Keycode.F5
    elif(key == Keycode.SIX):
        return Keycode.F6
    elif(key == Keycode.SEVEN):
        return Keycode.F7
    elif(key == Keycode.EIGHT):
        return Keycode.F8
    elif(key == Keycode.NINE):
        return Keycode.F9
    else:
        return key

#main loop
while True:
#    mod_keys = []
    reg_keys = []
    keypressed = False
    mod_keypressed = False

    for r in rows: #for each row
        r.value=1 #set row r to high
        for c in columns: #and then for each column
            if c.value: #if a keypress is detected (high row output --> switch closing circuit --> high column input)
                key = rows.index(r) * 8 + columns.index(c) #identify the key pressed via the index of the current row (r) and column (c)
                if mod_keymap[key] is not None:
                    mod_keypressed = True
                    mod_keys.append(mod_keymap[key])
                if keymap[key] is not None:
                    keypressed = True
                    reg_keys.append(keymap[key])
                    time.sleep(0.3) #delay a bit so that we don't get a load of duplicate presses

        r.value=0 #return the row to a low state, in preparation for the next row in the loop

    # Now instead of directly pressing the keys, we have stored them in arrays.
    # we must loop these and then press them.
    functionPressed = False
    # if(len(mod_keys) > 0):
#         for modifier_key in mod_keys:
#             if modifier_key is Keycode.F24:
#                 functionPressed = True
#             kbd.press(modifier_key)

    if(len(reg_keys) > 0):
        for reg_key in reg_keys:
            if functionPressed:
                kbd.press(ProcessFunctionKey(reg_key))
            else:
                kbd.press(reg_key)

        # once we are done and pressed everything in order, we can release all the keys
        kbd.release_all()

    if keypressed == False and mod_keypressed == False:
        kbd.release_all()

#TODO - CAPS LOCK TOGGLE
# Write your code here :-)

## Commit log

2025-04-07 Added QMK keyboard folder
    [matrix.csv]
2025-04-08 backed up log out put and python script before changing to try and create a circuitpython keyboard
2025-04-08 Removed older files and qmk stuff. Got a basic version of this working with circuitpython
2025-04-24 pcb design
    [bom.csv, designators.csv, pico-folio-keyboard-8x8-backup.kicad_pcb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]
2025-05-06 Refactored git repo with current state of project.
    [bom.csv, designators.csv, pico-folio-keyboard-8x8-backup.kicad_pcb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]
2025-05-09 Updated 3D models and print files
    [Bottom Row - With Lettering.3mf, Bottom Row.stl, FacePlate.stl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]
2025-05-10 added stl
    [Spacebar.stl]
2025-05-15 updated schematic and pcb to break out vbus and gnd for usb without bodge wires
    [pico-folio-keyboard.kicad_pcb, pico-folio-keyboard.kicad_sch]
2025-05-15 Tweaked settings to remove header from BOM and 3D view
